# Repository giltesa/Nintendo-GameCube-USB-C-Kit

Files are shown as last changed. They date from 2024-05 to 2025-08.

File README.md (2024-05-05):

# Nintendo GameCube: USB-C Kit

The **Nintendo GameCube: USB-C Kit** is a board that allows to replace the original power connector for a modern and standard USB-C.

**If your original connector / power supply is too old or damaged** and you need a new one, or **if you would like to power up your Nintendo GameCube with a standard USB-C PD charger**, such as the charger for your phone, or laptop, you can do so with this kit.

## HOW DOES IT WORK?

The **USB-C Power Delivery technology (USB-C PD)** allows for communication between the device and the charger, enabling the negotiation of the voltage to be supplied through the USB-C cable. In this case, the microchip included in this board is configured to request 12V, signaling to the charger that it requires 12V to operate. If the charger is compatible, it will supply the requested voltage. If it’s not compatible, nothing will happen, and the Nintendo GameCube won’t be able to power on.

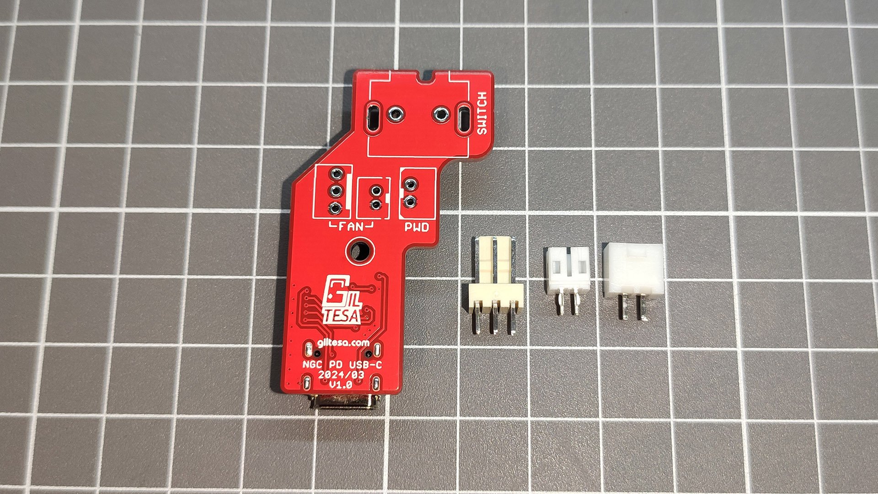
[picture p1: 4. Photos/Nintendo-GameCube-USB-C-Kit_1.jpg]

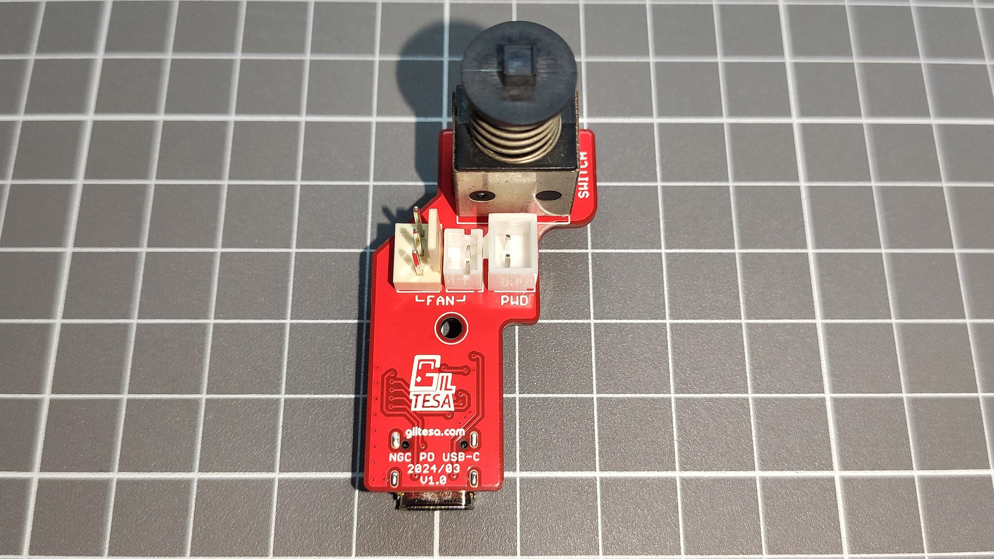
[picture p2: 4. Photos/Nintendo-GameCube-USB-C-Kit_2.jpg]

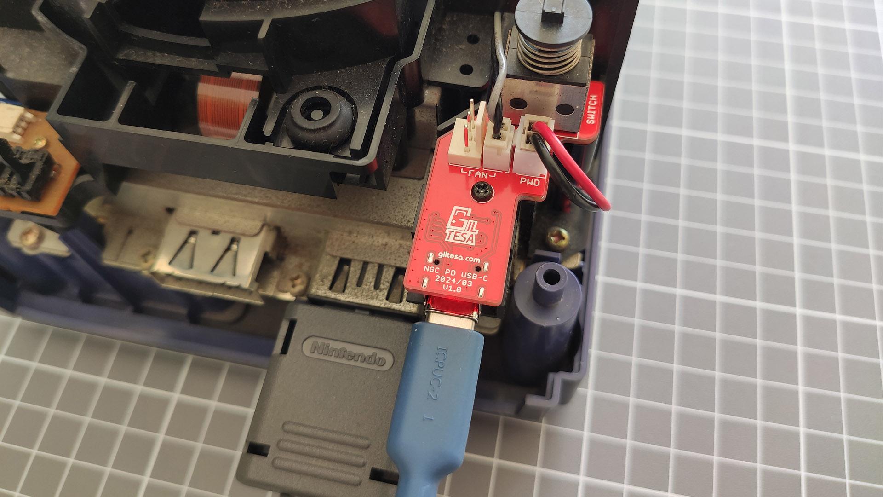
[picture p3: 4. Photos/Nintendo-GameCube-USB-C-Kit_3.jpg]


## Would you like it?

[**Nintendo GameCube: USB-C Kit**](https://shop.giltesa.com/?p=1995)

## License

This project is licensed under a **Creative Commons** license:
**[Attribution-NonCommercial-ShareAlike 4.0 International (CC BY-NC-SA 4.0) ](https://creativecommons.org/licenses/by-nc-sa/4.0/)**

Check the [LICENSE.md](LICENSE.md) for more information.

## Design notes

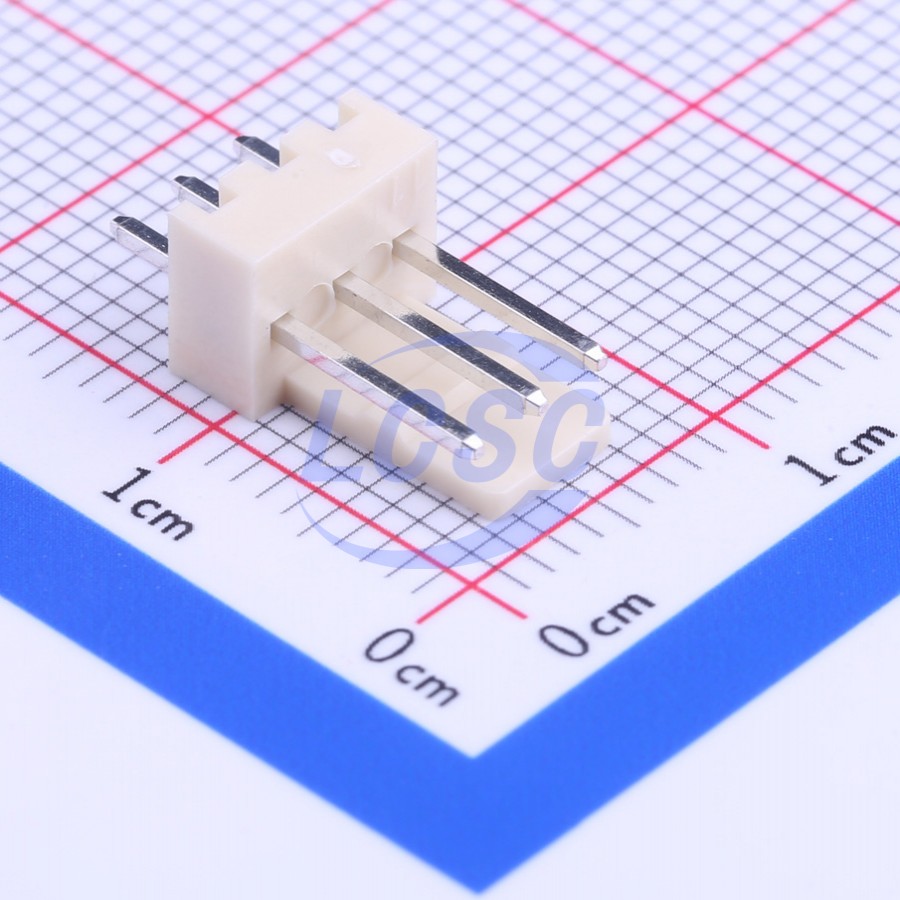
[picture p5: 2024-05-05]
3. Documentation/Datasheet/Molex TX3 FAN/20180914_Ckmtw-Shenzhen-Cankemeng-W-2510S03P-0000_C132505_front.jpg

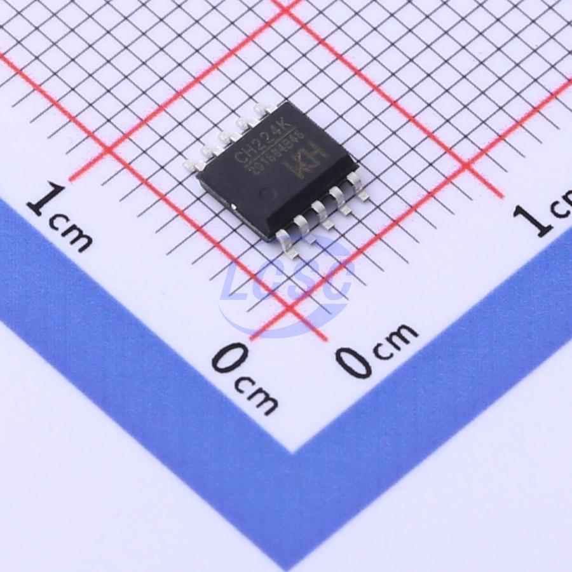
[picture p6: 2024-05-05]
3. Documentation/Datasheet/PD/20230201_WCH-Jiangsu-Qin-Heng-CH224K_C970725_front.jpg

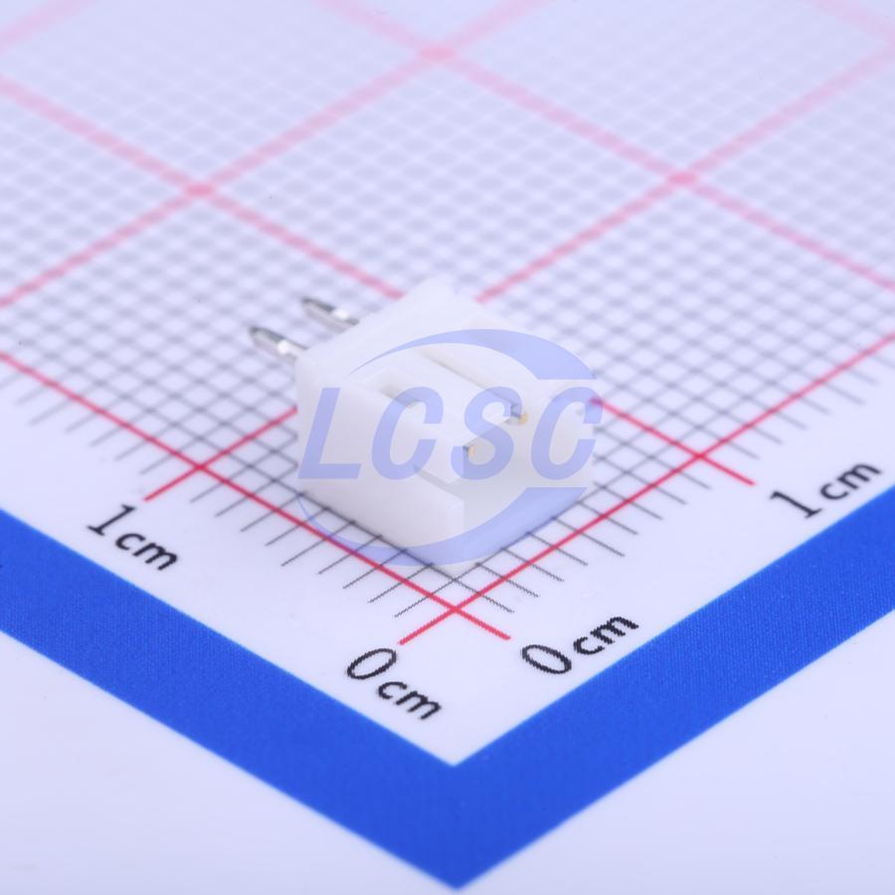
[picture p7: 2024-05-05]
3. Documentation/Datasheet/NGC - FAN/20230102_JST-B2B-PH-K-S-LF-SN_C131337_front.jpg

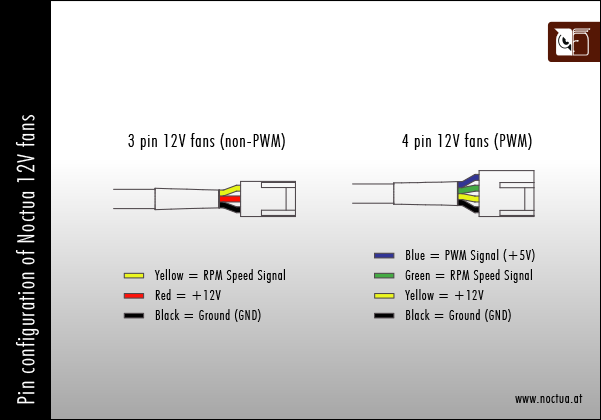
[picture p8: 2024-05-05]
3. Documentation/Datasheet/Molex TX3 FAN/noctua_pin_configuration_12v_fans.png

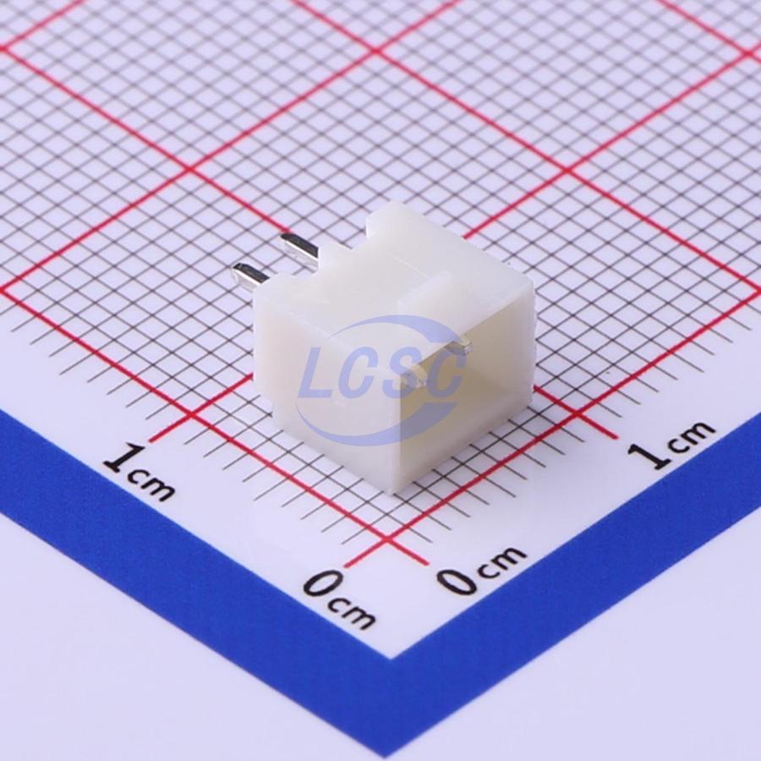
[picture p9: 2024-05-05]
3. Documentation/Datasheet/NGC - POWER/20230119_XFCN-M2501VF-02P_C492487_front.jpg

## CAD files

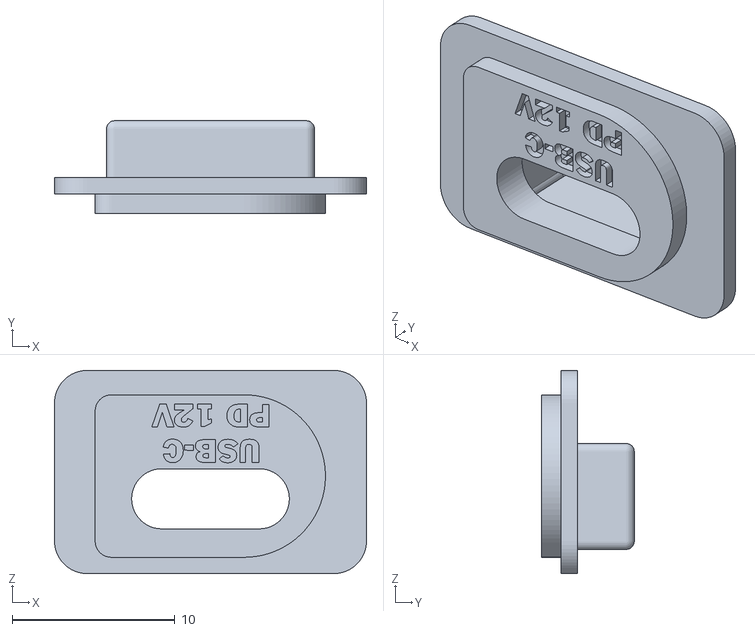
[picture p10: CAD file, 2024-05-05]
2. Renders, 3D models/Cap/Game Cube USB-C v33.stl
19.2 x 5.70 x 12.5

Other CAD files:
2. Renders, 3D models/Cap/Game Cube USB-C v33.f3d
2. Renders, 3D models/Game Cube USB-C v1.1.skp

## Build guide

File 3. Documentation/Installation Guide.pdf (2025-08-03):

# Nintendo GameCube USB-C Kit

PRODUCT

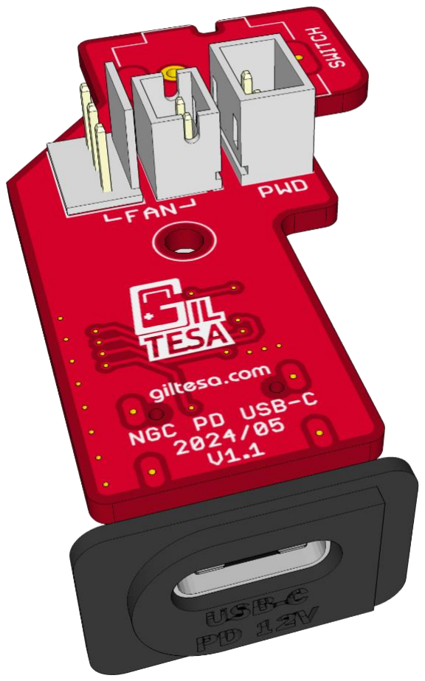
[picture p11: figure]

HTTPS://SHOP.GILTESA.COM/PRODUCT/NINTENDO-GAMECUBE-USB-C-KIT

# PLEASE READ THROUGH THESE INSTRUCTIONS

ENTIRELY BEFORE ATTEMPTING TO INSTALL.

# WARNING: IF YOU ARE NOT COMFORTABLE WITH SOLDERING, OR PERFORMING ANY STEP IN THIS

GUIDE, DO NOT PERFORM THE INSTALL YOURSELF.

# FIND SOMEONE WHO IS COMFORTABLE TO DO IT FOR

YOU.

INDEX

# Description

The Nintendo GameCube: USB-C Kit is a board that allows to replace the original power connector for a modern and standard USB-C.

If your original connector / power supply is too old or damaged and you need a new one, or if you would like to power up your Nintendo GameCube with a standard USB-C PD charger, such as the charger for your phone, or laptop, you can do so with this kit.

# HOW DOES IT WORK?

The USB-C Power Delivery technology (USB-C PD) allows for communication between the device and the charger, enabling the negotiation of the voltage to be supplied through the USB-C cable. In this case, the microchip included in this board is configured to request 12V, signaling to the charger that it requires 12V to operate. If the charger is compatible, it will supply the requested voltage. If it’s not compatible, nothing will happen, and the Nintendo GameCube won’t be able to power on.

# FEATURES

- Exact shape for Nintendo GameCube.
- External power through USB-C.
- Extra fan connector for computer fans such as the Noctua NF-A4x10.

# INCLUDED

- 1 USB-C board.
- 1 Power connector.
- 1 Fan connector.
- 1 Fan connector of 3 pines.
- 1 Plastic cap for the USB-C board.

# Recommended / REQUIRED (NOT INCLUDED)

- Original push button switch from the board to be replaced.
- 4.5mm gamebit (https://www.aliexpress.com/item/1005002101234227.html) and phillips screwdrivers.
- Tin soldering iron.
- Tin.
- Flux.
- Desoldering pump.
- Isopropyl alcohol.

# NOTES

This kit requires a special power supply that supports power delivery (PD) with an output of 12V and a minimum of 3A. Generally, laptop power supplies and some phone chargers can be used. If you don’t have any, take a look at the list of recommendations. (The Nintendo Switch power supply is not compatible because it doesn’t supply 12V).

- Ikea SJÖSS 45W 12V 3A, (https://www.ikea.com/es/en/p/sjoss-45w-2-port-usb-charger-fast-charging-80574438/) 13€

You will also need a USB-C to USB-C cable for PD. If you don’t have one, these will work:

- Ikea SITTBRUNN USB-C to USB-C 1m (https://www.ikea.com/es/en/p/sittbrunn-usb-c-to-usb-c-blue-30546650/)
- Ikea LILLHULT USB-C to USB-C 1.5 m (https://www.ikea.com/es/en/p/lillhult-usb-c-to-usb-c-dark-grey-50527603/)

# Board details

The board doesn't come fully assembled; there are 3 connectors and the original GameCube switch missing to be soldered. Below is the position of each component:

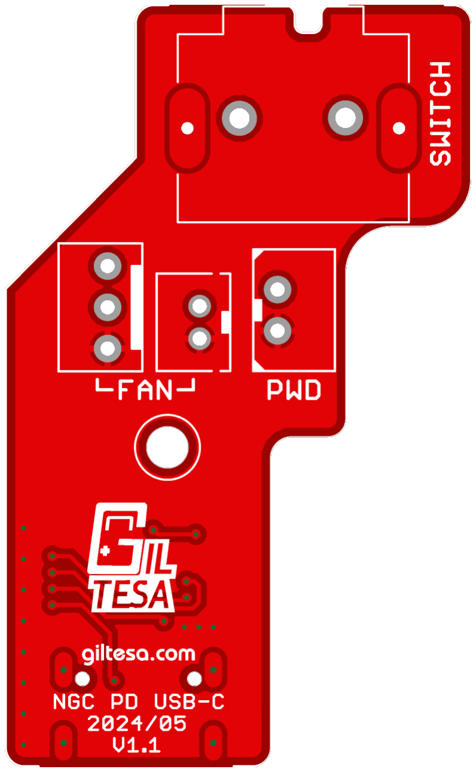
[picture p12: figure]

- FAN: | 3-pin connector for computer fan; the Noctua NF-A4x10 is recommended. (Optional)
- FAN: | 2-pin connector for the original GC fan.
- POWER: 2-pin connector to power the GC.
- SWITCH: Position where the original GC switch is soldered.

# INSTALLATION STEPS

Please, carefully read the following steps for a successful installation.

## Pre installation Steps

Before the installation, your GC may need some extra steps to have it ready for the kit.

1. Disassembly the GAMECUBE

Nintendo products in general use two kind of screws. The first one called gamebit to close the shell, and the second one called phillips to hold the main board to the shell.

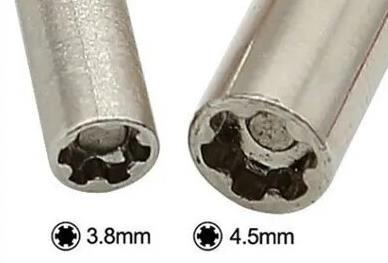
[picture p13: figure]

Gamebit screwdriver
Use the 4.5mm gamebit screwdriver to open the shell and remove the 4 gamebit screws.

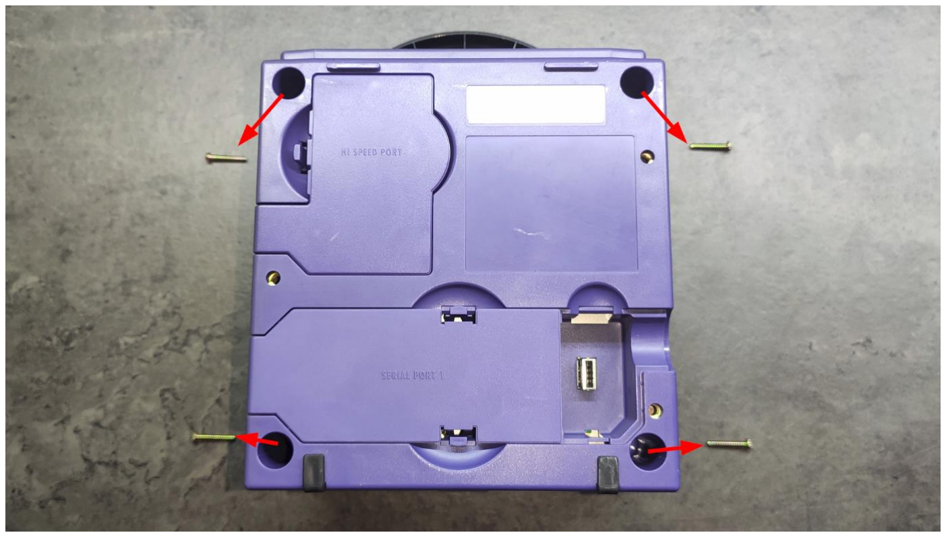
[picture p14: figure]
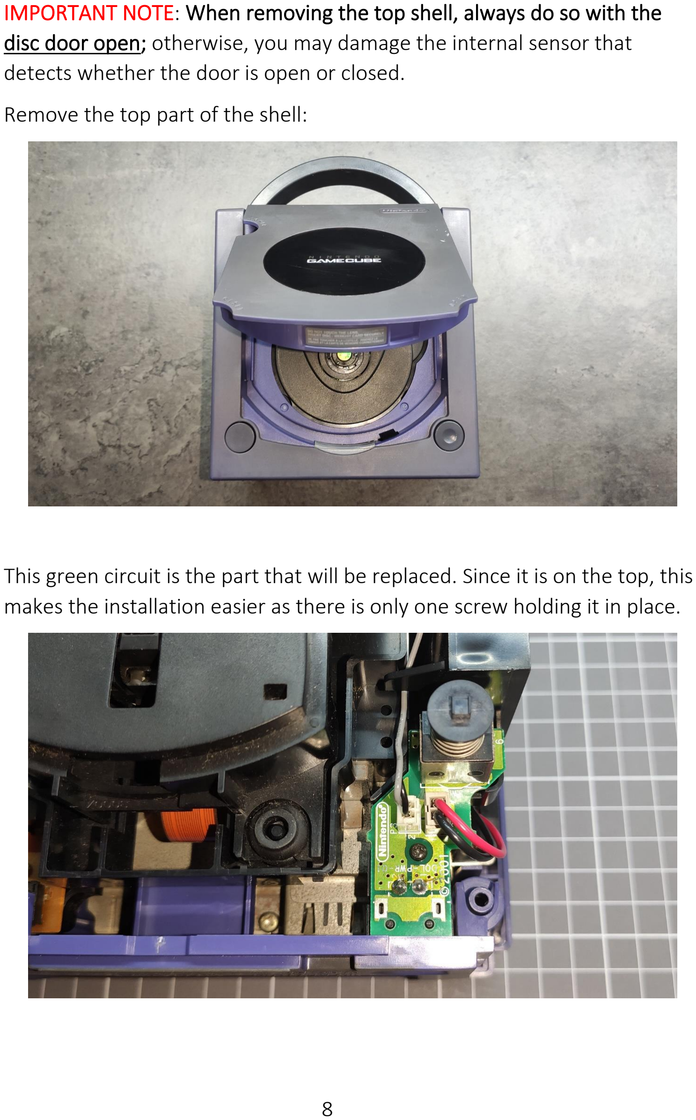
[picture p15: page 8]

IMPORTANT NOTE: When removing the top shell, always do so with the disc door open; otherwise, you may damage the internal sensor that detects whether the door is open or closed.

Remove the top part of the shell:

This green circuit is the part that will be replaced. Since it is on the top, this makes the installation easier as there is only one screw holding it in place.

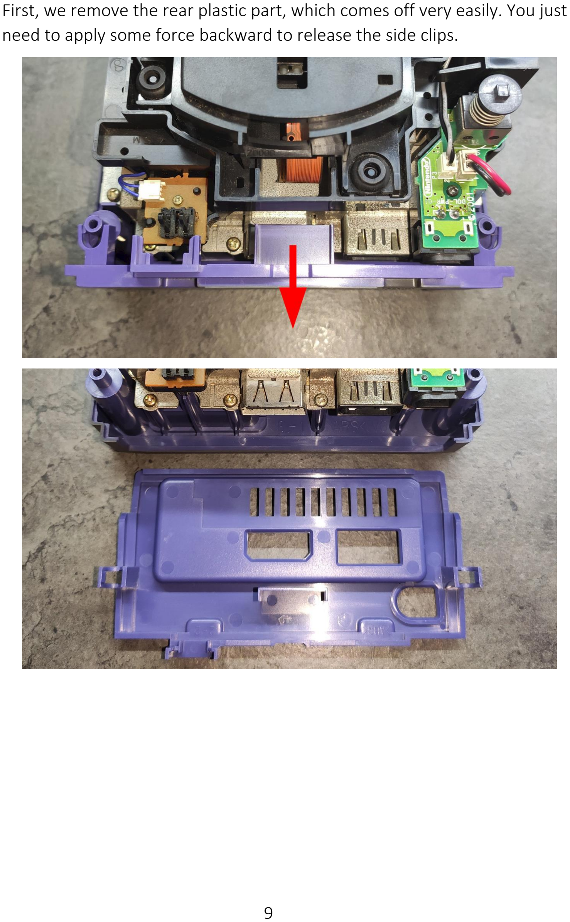
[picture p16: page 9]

First, we remove the rear plastic part, which comes off very easily. You just need to apply some force backward to release the side clips.

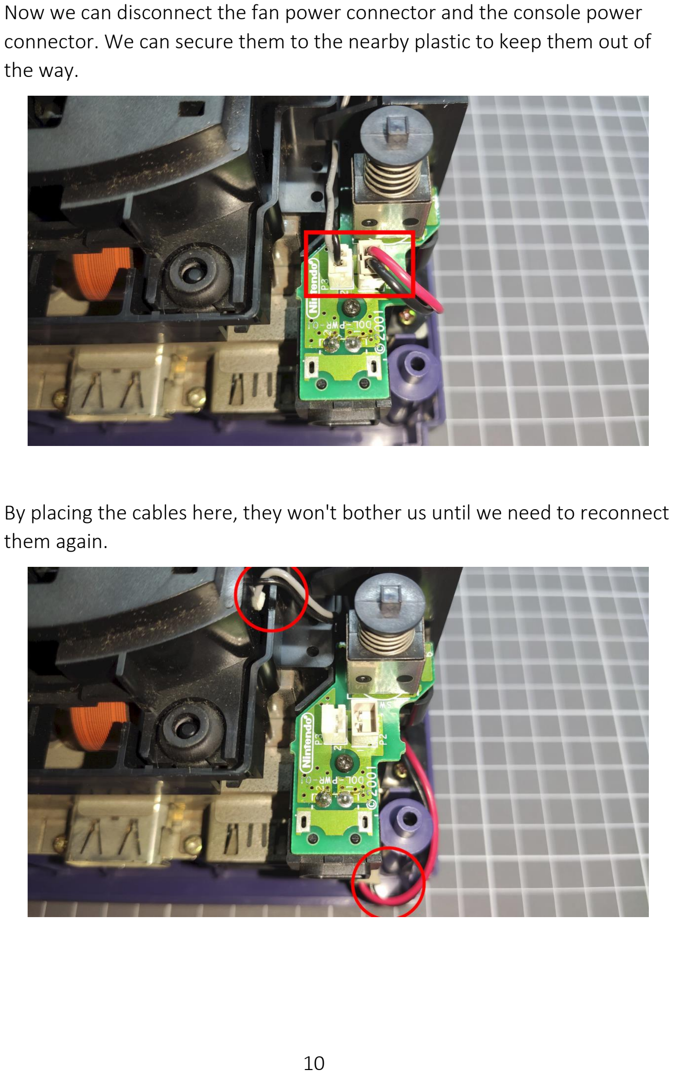
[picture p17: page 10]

Now we can disconnect the fan power connector and the console power connector. We can secure them to the nearby plastic to keep them out of the way.

By placing the cables here, they won't bother us until we need to reconnect them again.

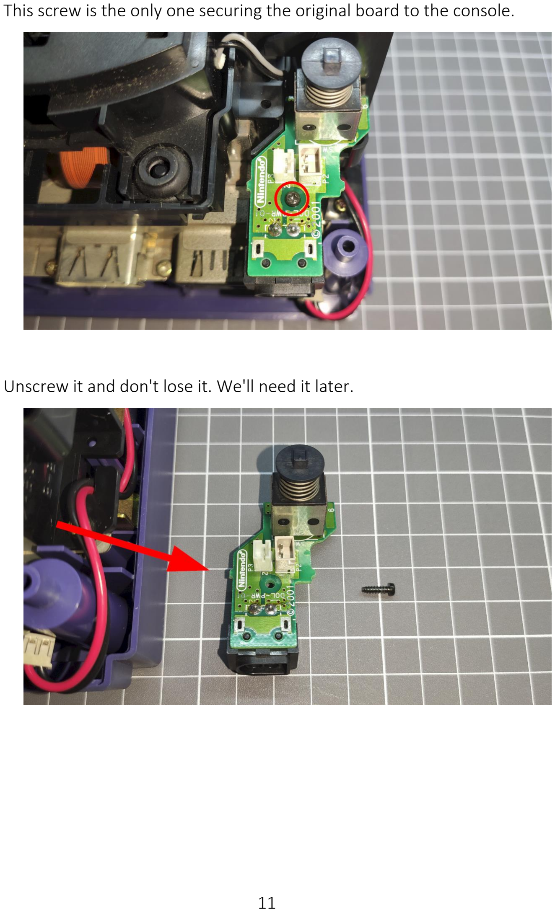
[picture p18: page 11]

This screw is the only one securing the original board to the console.

Unscrew it and don't lose it. We'll need it later.

2. Retrieve the button from the original board

The power button from the original board needs to be retrieved for the new board. Use a soldering iron and a desoldering pump to extract it. Once done, keep it for later use.

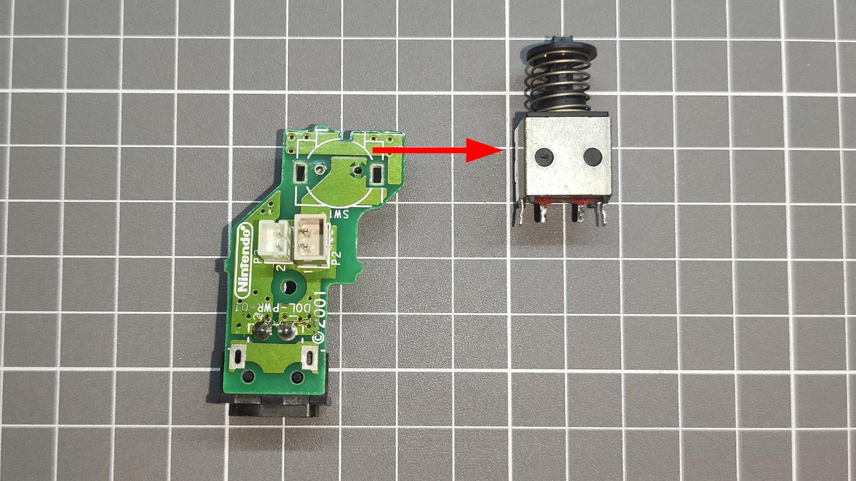
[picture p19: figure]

## installation Steps

1. Board assembly

Now it's time to finish assembling the new board. The kit includes 3 connectors as well as the plastic cap.

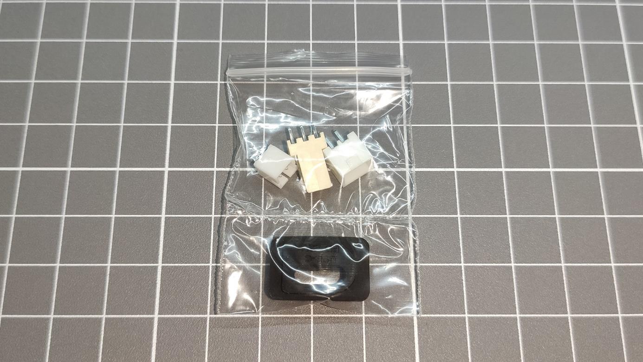
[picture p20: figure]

The plastic is separated from the rest to prevent scratching with the connectors. You can keep it in the bag until you need it.

Once you need it, You will need to tear the bag to take it out as it is thermally sealed.

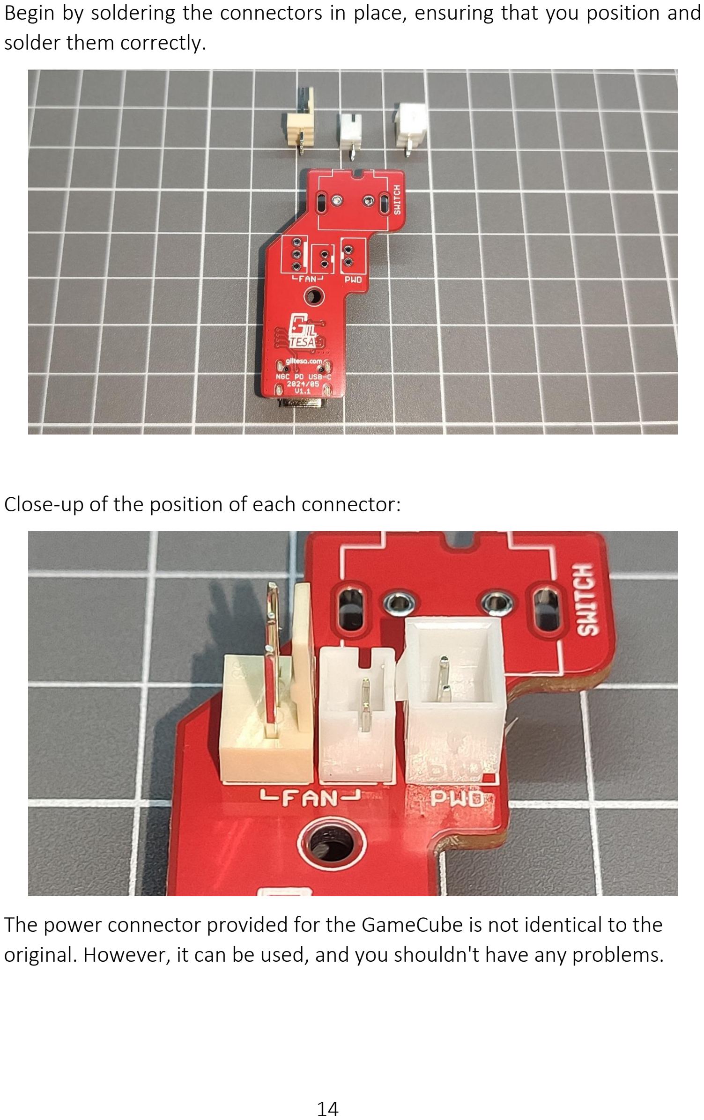
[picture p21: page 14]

Begin by soldering the connectors in place, ensuring that you position and solder them correctly.

Close-up of the position of each connector:

The power connector provided for the GameCube is not identical to the original. However, it can be used, and you shouldn't have any problems.

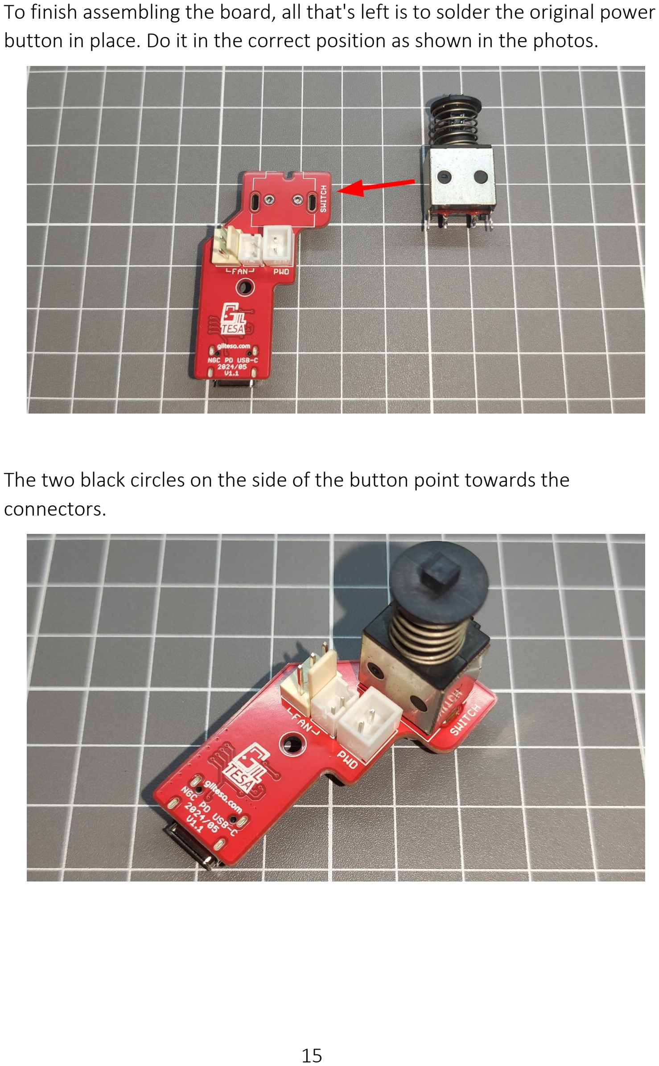
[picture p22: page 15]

To finish assembling the board, all that's left is to solder the original power button in place. Do it in the correct position as shown in the photos.

The two black circles on the side of the button point towards the connectors.

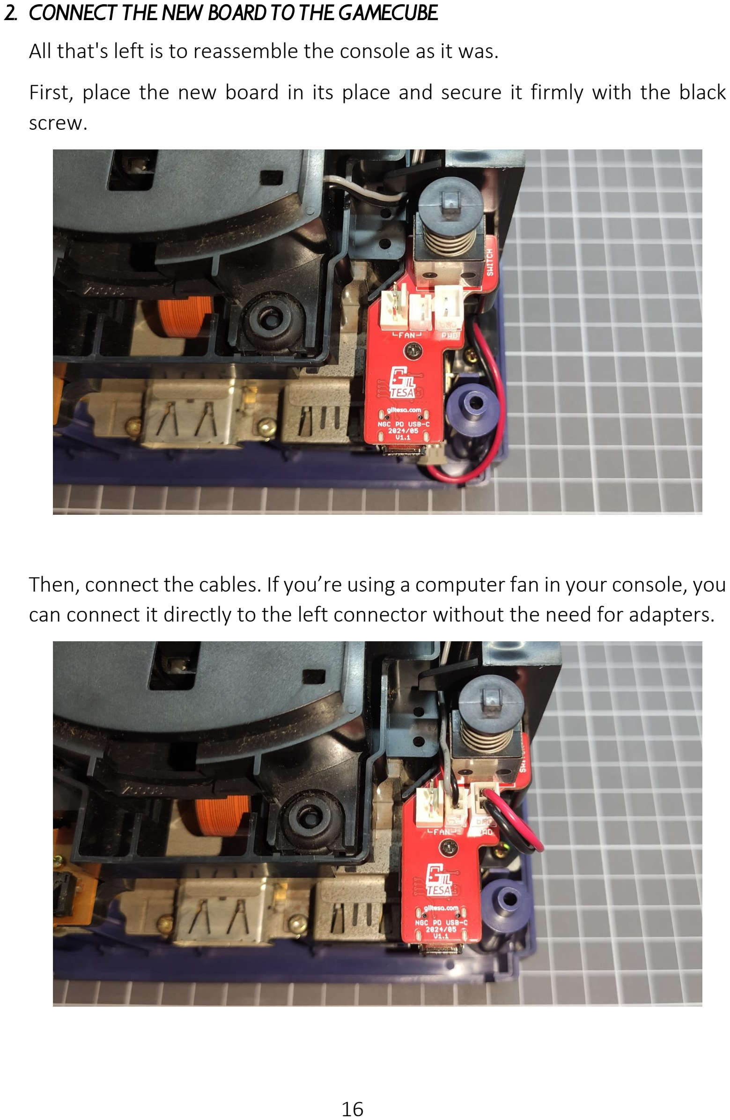
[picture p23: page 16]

2. Connect the new board to the GameCube

All that's left is to reassemble the console as it was.

First, place the new board in its place and secure it firmly with the black screw.

Then, connect the cables. If you’re using a computer fan in your console, you can connect it directly to the left connector without the need for adapters.

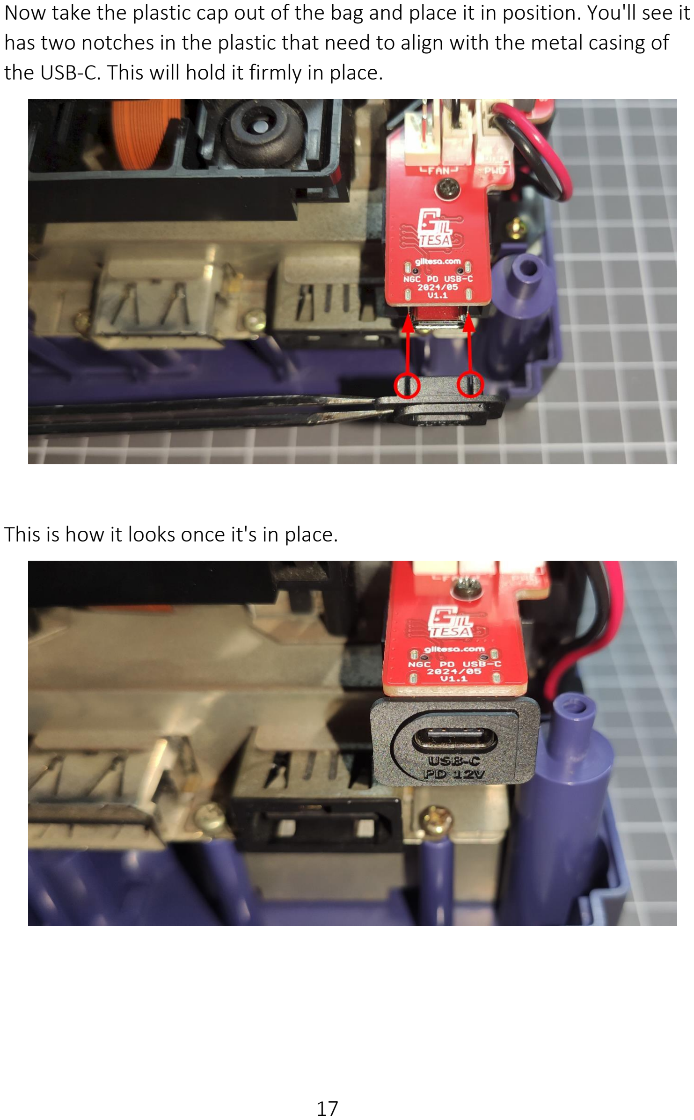
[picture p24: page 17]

Now take the plastic cap out of the bag and place it in position. You'll see it has two notches in the plastic that need to align with the metal casing of the USB-C. This will hold it firmly in place.

This is how it looks once it's in place.

And this is how it looks once the rear plastic cover of the console is in place and the USB-C cable is connected.

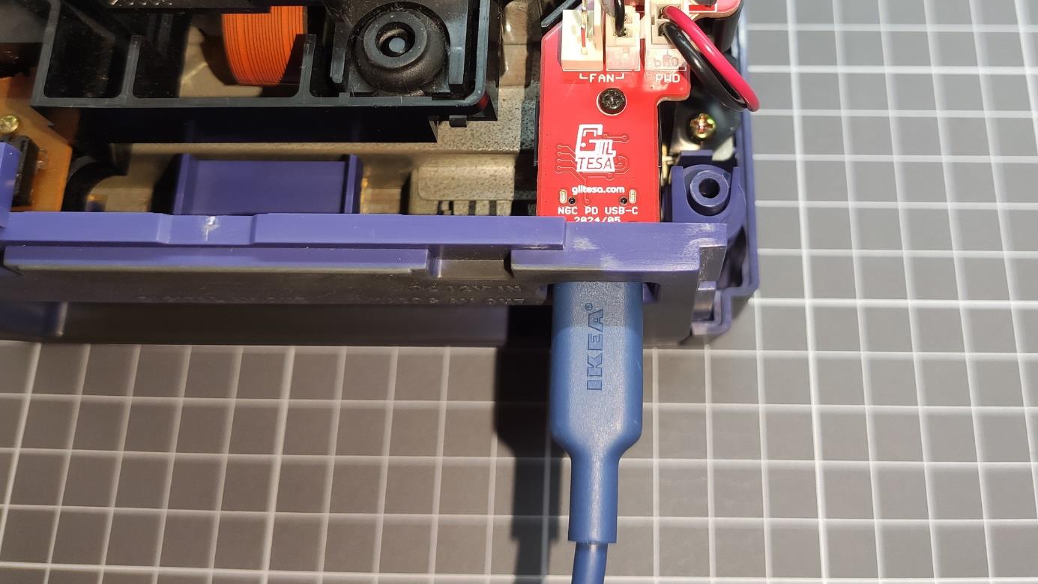
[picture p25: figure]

You can now put the top part of the case back in place and secure it with the screws.

IMPORTANT NOTE: When putting back the top shell, always do so with the disc door open; otherwise, you may damage the internal sensor that detects whether the door is open or closed.

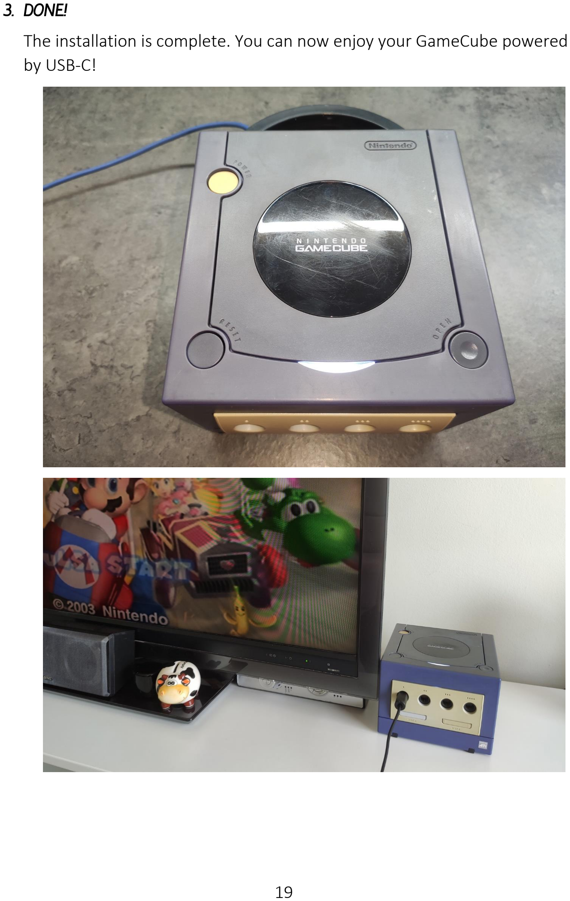
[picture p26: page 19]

3. Done!

The installation is complete. You can now enjoy your GameCube powered by USB-C!

# Frequently Asked Questions – FAQ

Is there a recommended power supply?
Any USB-C Power Delivery charger with a 12V 3A output is more than sufficient. We used the Ikea SJÖSS 45W (https://www.ikea.com/es/en/p/sjoss-45w-2-port-usb-charger-fast-charging-80574438/) (12V 3A) for all our tests.

The GameCube doesn't turn on.
Make sure you are using a USB-C power supply that can provide an output voltage of 12V and an electric current of at least 3A.

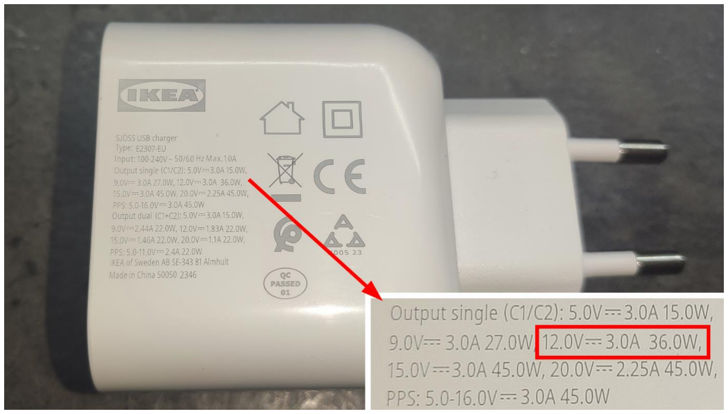
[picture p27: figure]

My power supply doesn’t have a 12V output.
Power Delivery chargers can supply a wide range of voltages: 5 V, 9 V, 12 V, 15 V, and 20 V. However, they’re not required to support all of them, a charger might offer 5 V, 9 V, and 15 V but not 12 V or 20 V, or it might support everything except 12 V.

That’s why it’s important to check whether your charger actually supports 12 V output.

The GameCube still won't turn on.
If it still doesn't work, you will need to use a multimeter to check that power is reaching the circuit and that the original GC button you used is not faulty.
1) Connect the power supply and USB-C cable to the board, then use the multimeter in continuous voltage measurement mode to check if you have 12V here. (First image)
2) Now perform the same test at the button's output. This way, you can check if the button opens and closes the circuit correctly. (Second image)

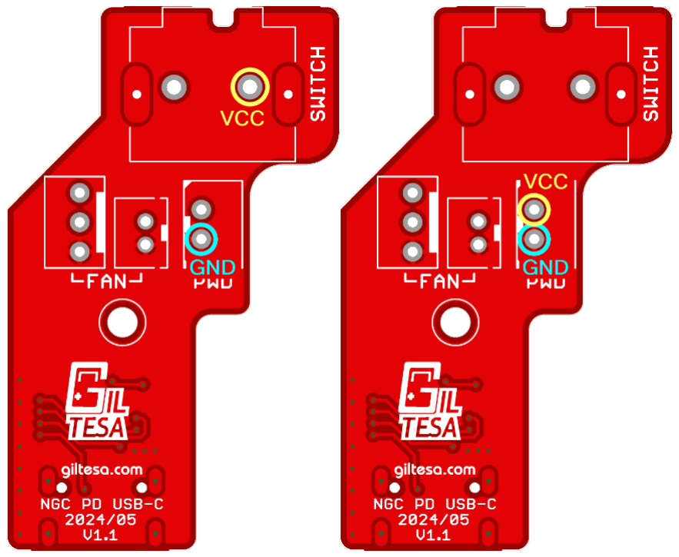
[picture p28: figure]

Can this kit be used with other mods?
Of course, as long as you use the appropriate power supply, 12V and 3A, then you can use any other mod or accessory you would normally use with the original power supply.

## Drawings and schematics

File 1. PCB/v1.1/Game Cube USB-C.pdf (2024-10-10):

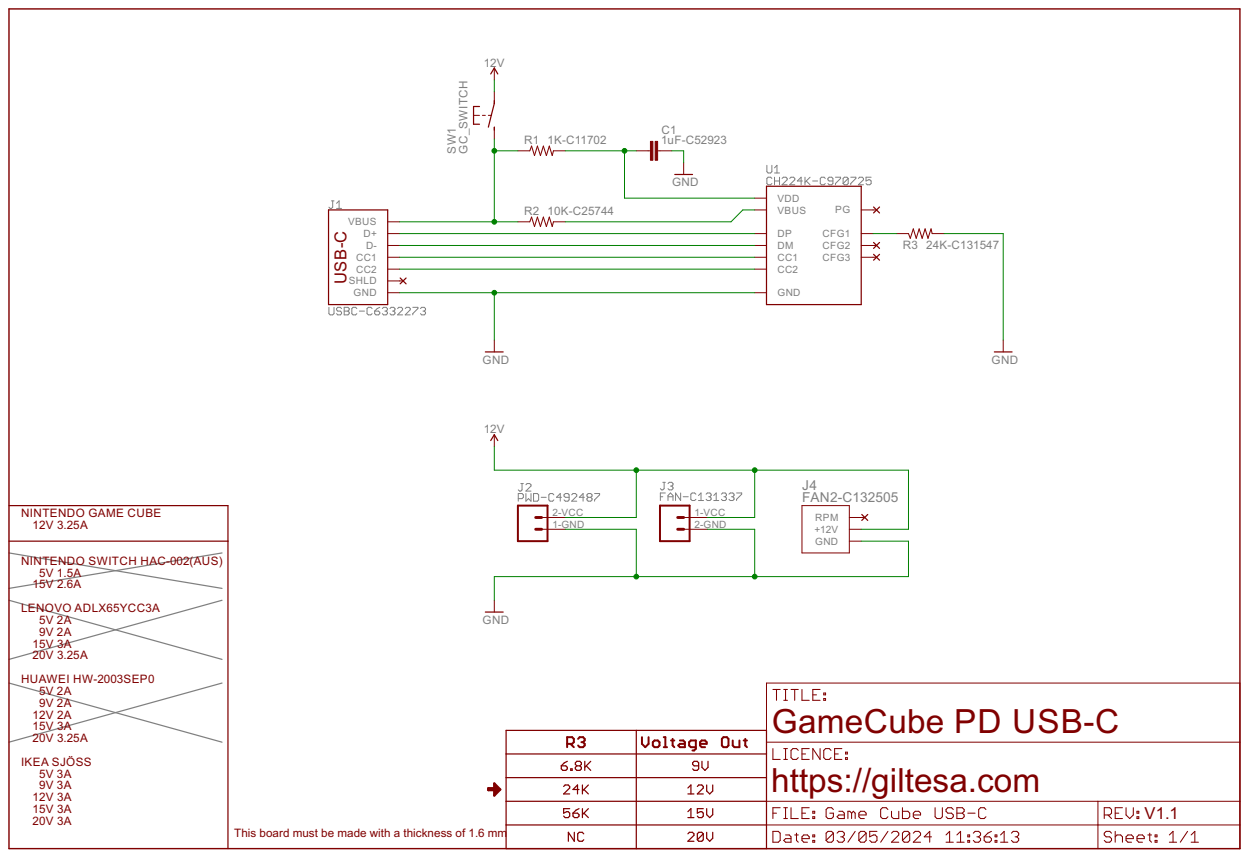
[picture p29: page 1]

This board must be made with a thickness of 1.6 mm

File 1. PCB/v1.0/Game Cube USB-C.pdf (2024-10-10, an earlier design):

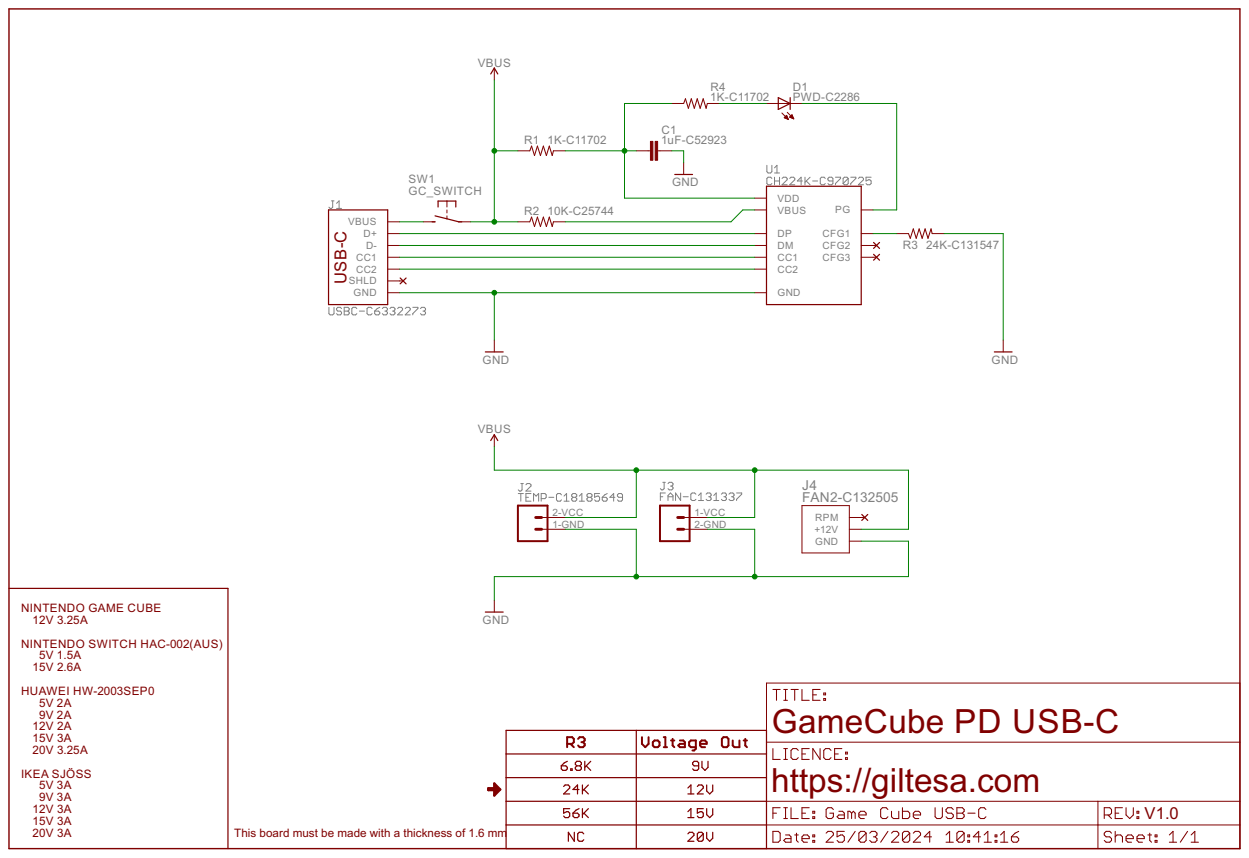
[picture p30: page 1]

This board must be made with a thickness of 1.6 mm

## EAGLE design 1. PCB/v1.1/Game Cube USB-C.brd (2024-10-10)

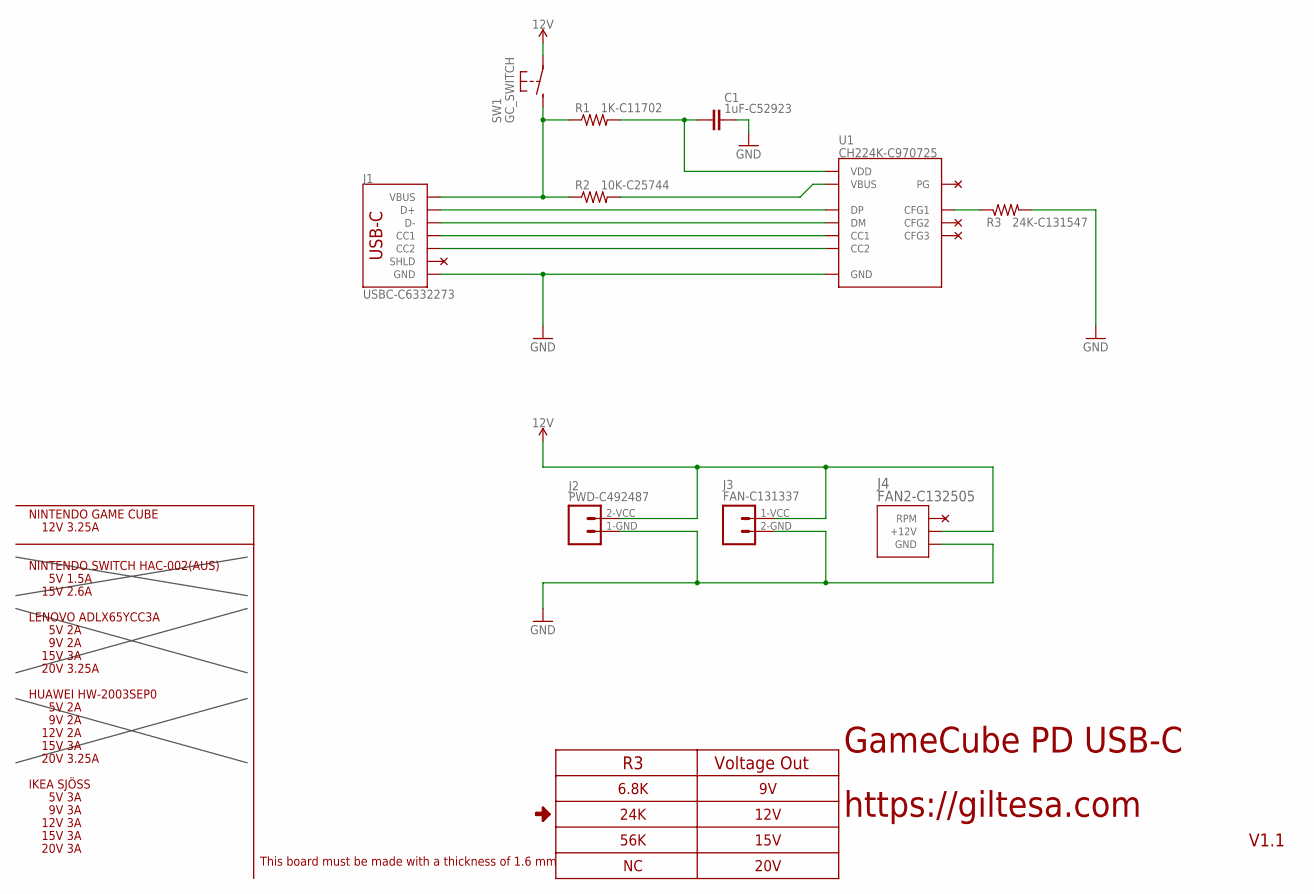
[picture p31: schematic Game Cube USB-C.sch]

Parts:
C1: 1uF-C52923; C0402_S
J1: USBC-C6332273; USB-C_16P_3MM
J2: PWD-C492487; GC_PWD_CONNECTOR
J3: FAN-C131337; GC_FAN_CONNECTOR
J4: FAN2-C132505; MOLEX-W-2510S03P
R1: 1K-C11702; R0402
R2: 10K-C25744; R0402
R3: 24K-C131547; R0402
SW1: GC_SWITCH
U1: CH224K-C970725; ESSOP10

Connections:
12V: J2.2-VCC (2), J3.1-VCC (1), J4.P2-12V (+12V), SW1.P$1 (1)
CC1: J1.A5-CC1 (CC1), U1.7 (CC1)
CC2: J1.B5-CC2 (CC2), U1.6 (CC2)
D+: J1.A6-DP1 (D+), J1.B6-DP2 (D+), U1.4 (DP)
D-: J1.A7-DN1 (D-), J1.B7-DN2 (D-), U1.5 (DM)
GND: C1.2, J1.GND1 (GND), J1.GND2 (GND), J2.1-GND (1), J3.2-GND (2), J4.P3-GND (GND), R3.2, U1.0 (GND)
unnamed: R3.1, U1.9 (CFG1)
unnamed: R2.2, U1.8 (VBUS)
VBUS: J1.VBUS1 (VBUS), J1.VBUS2 (VBUS), R1.1, R2.1, SW1.P$2 (2)
VDD: C1.1, R1.2, U1.1 (VDD)

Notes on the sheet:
GameCube PD USB-C
https://giltesa.com
V1.1
This board must be made with a thickness of 1.6 mm
NINTENDO SWITCH HAC-002(AUS)
5V 1.5A
15V 2.6A
HUAWEI HW-2003SEP0
5V 2A
9V 2A
12V 2A
15V 3A
20V 3.25A
NINTENDO GAME CUBE
12V 3.25A
Voltage Out
6.8K
24K
56K
12V
15V
20V
LENOVO ADLX65YCC3A
IKEA SJÖSS
5V 3A
9V 3A
12V 3A
20V 3A

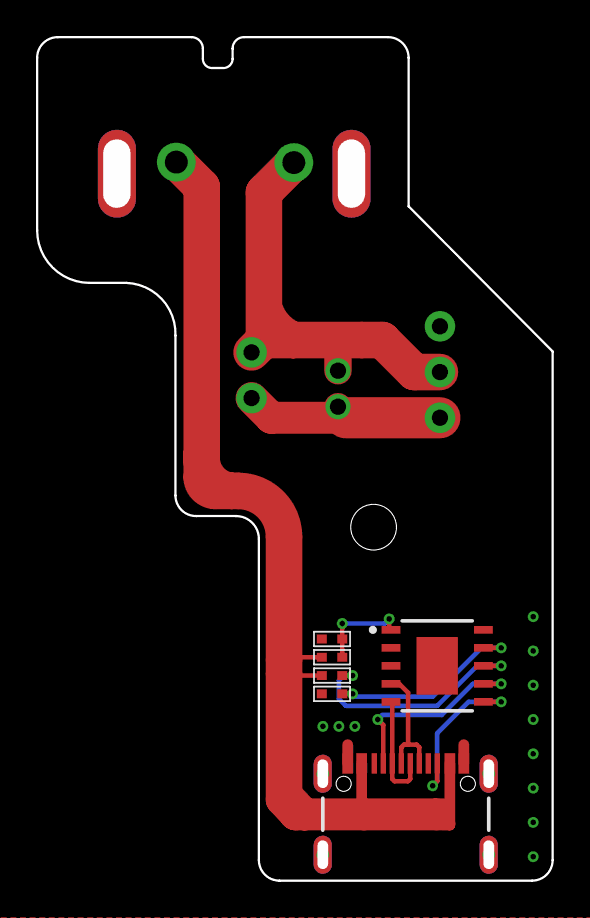
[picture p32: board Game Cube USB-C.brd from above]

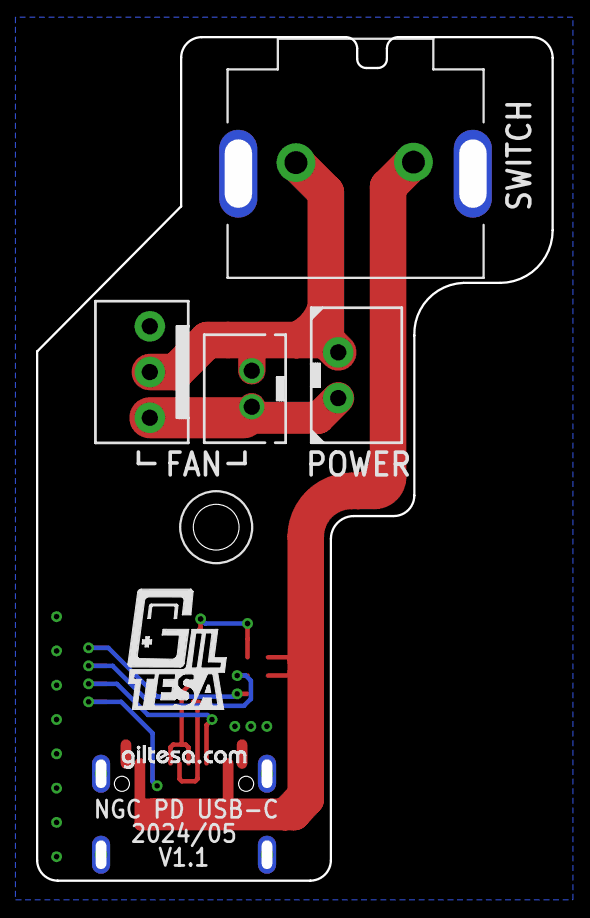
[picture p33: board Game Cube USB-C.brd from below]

Board: 2 copper layers, 28.6 x 46.9 mm, 13 parts (6 on the bottom side), 10 nets.

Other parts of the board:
U$6: GC_DRILL_SCREW
U$8: GILTESA_LOGO_MASK_7MM
U$28: GILTESA.COM_MASK_7MM

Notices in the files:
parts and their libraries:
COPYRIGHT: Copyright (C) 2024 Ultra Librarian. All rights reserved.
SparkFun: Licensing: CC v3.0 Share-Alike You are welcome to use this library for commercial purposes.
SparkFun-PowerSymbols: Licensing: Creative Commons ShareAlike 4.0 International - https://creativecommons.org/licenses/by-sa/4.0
